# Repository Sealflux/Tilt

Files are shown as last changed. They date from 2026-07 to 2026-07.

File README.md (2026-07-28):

## Tilt
-- I put photo here once I have!

## Description
A motion-controlled keychain game console. Built around the Seeed XIAO ESP32C3 with an SSD1306 OLED and MPU6050 accelerometer. Planning to make a ball tilt game maybe

## Features
- Its a game console with an accelerometer in it!
- Play cool game or design one yourself!
- Put it on your backpack as its supposed to be a keychain thingabob
- Rechargeable Battery!
## Hardware
- Seeed Xiao ESP32-C3
- SSD1306 128x64 OLED (I2C)
- Tactile Push Button
- 3D accelerometer and 3D magnetometer
- Buzzer
- Mystery LiPo Battery(Haven't decided which one on amazon yet)
- 3D-printed case

## Bill of Materials (BOM)

| Qty | Part Name | Designator | Costs | Link/LCSC Number |
|:---:|---|:---:|:-----:|---|
| 1 | Seeed XIAO ESP32-C3 | U2 | $6.35 | [Link](https://wiki.seeedstudio.com/XIAO_ESP32C3_Getting_Started/) |
| 1 | LiPo Battery | BT1 | | I'll find one on amazon eventually |
| 1 | 0.96" OLED Display | U3 | $2.24 | [C5248080](https://www.lcsc.com/product-detail/C5248080.html) |
| 1 | Tactile Button | SW1 | $0.56 | [C2913653](https://www.lcsc.com/product-detail/C2888493.html) |
| 1 | Accelerometer | U1 | $4.04 | [C2913653](https://www.lcsc.com/product-detail/C2913653.html) |
| 1 | Capacitor – 220 nF | C3 | $0.96 | [C412252](https://www.lcsc.com/product-detail/C412252.html) |
| 2 | Ceramic Capacitor – 100 nF | C1,C2 | $0.88 | [C60474](https://www.lcsc.com/product-detail/C60474.html) |
| 1 | Aluminum Capacitor – 10 µF | C4 | $0.74 | [C192100](https://www.lcsc.com/product-detail/C192100.html) |
| 1 | Buzzer | BUZZER1 | $0.32 | [C49246964](https://www.lcsc.com/product-detail/C49246964.html) |
| 1 | 3D Printed Case | N/A | Idk whatever fliament you use makes costs dependent | N/A |
| 1 | Shipping | $52.39 | $6.20(Seeed) + $11.33(LCSC) + $6.99(Amazon) + $27.87(JLCPCB) | N/A |

## Steps To Reproduce
1. Order the PCB from whatever PCB manufacturer you like, download gerbers.zip from Production folder
2. 3D print the case, Its in the production folder. Use whatever filament you want, probably PLA.
3. Order the parts using the BOM ^^^
4. Solder the parts onto the PCB
5. Connect the LiPo battery to the PCB
6. Flash your firmware/game onto it!
7. Assemble case, sand the surfaces of top and bottom and then superglue or idk use tape. I didn't add screws for some reason.
8. Press the button and play the game!
## Firmware
this is hardware!
## Schematic

## PCB

## PCBA

## Case

## Side View Below

## Demo(Idk probably after horizons event)

Link: (TBD After I finish hardware)

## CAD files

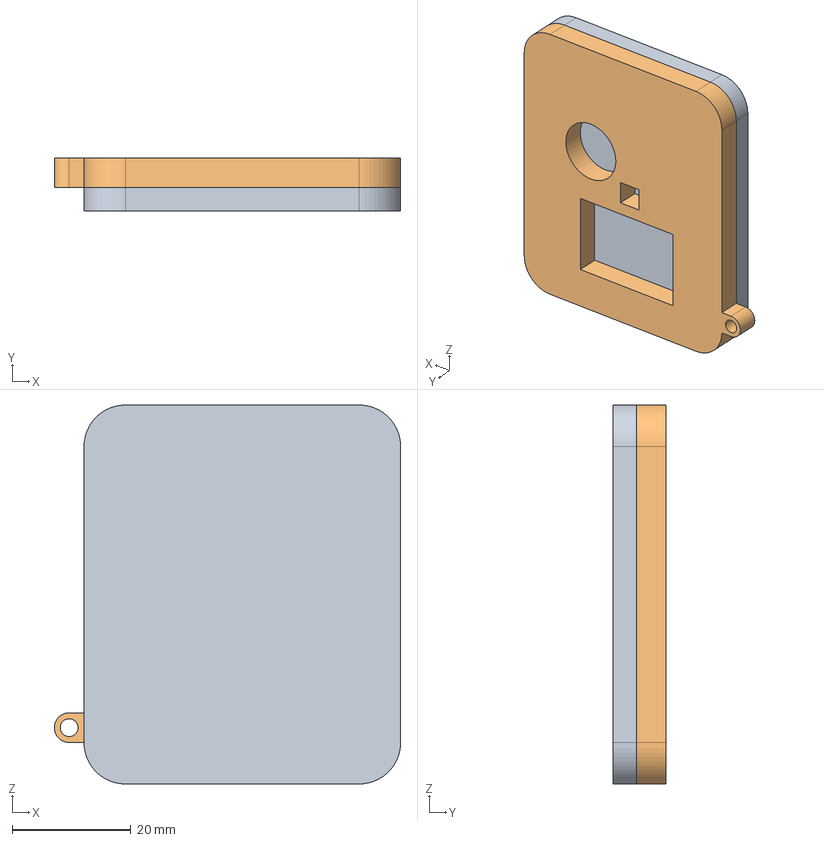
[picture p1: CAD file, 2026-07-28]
CAD/TiltCase.step
58.4 x 9.00 x 63.9 mm

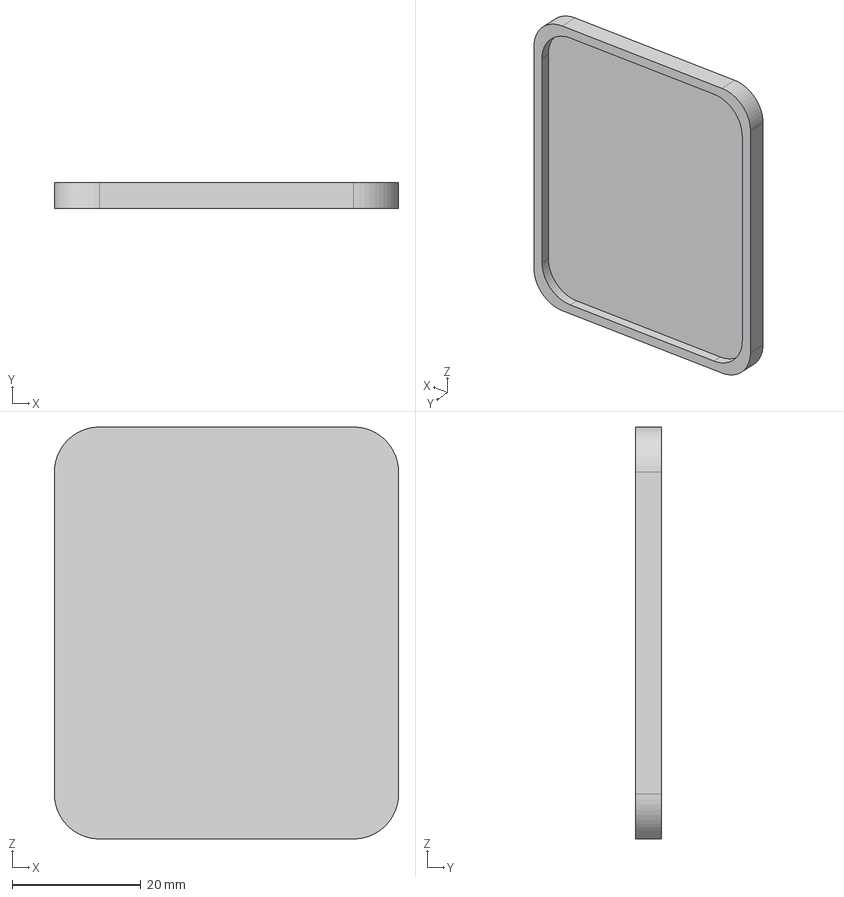
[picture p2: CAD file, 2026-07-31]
Production/Bottom.step
53.4 x 4.00 x 63.9 mm

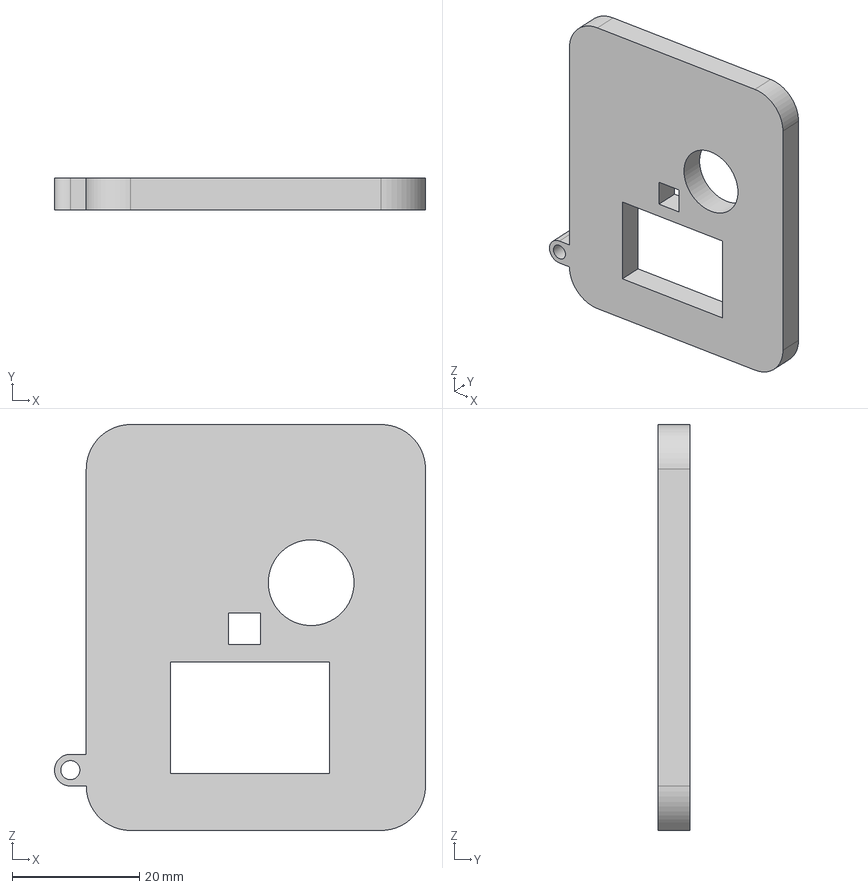
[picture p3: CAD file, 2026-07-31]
Production/Top.step
58.4 x 5.00 x 63.9 mm

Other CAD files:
CAD/TiltCase.f3d

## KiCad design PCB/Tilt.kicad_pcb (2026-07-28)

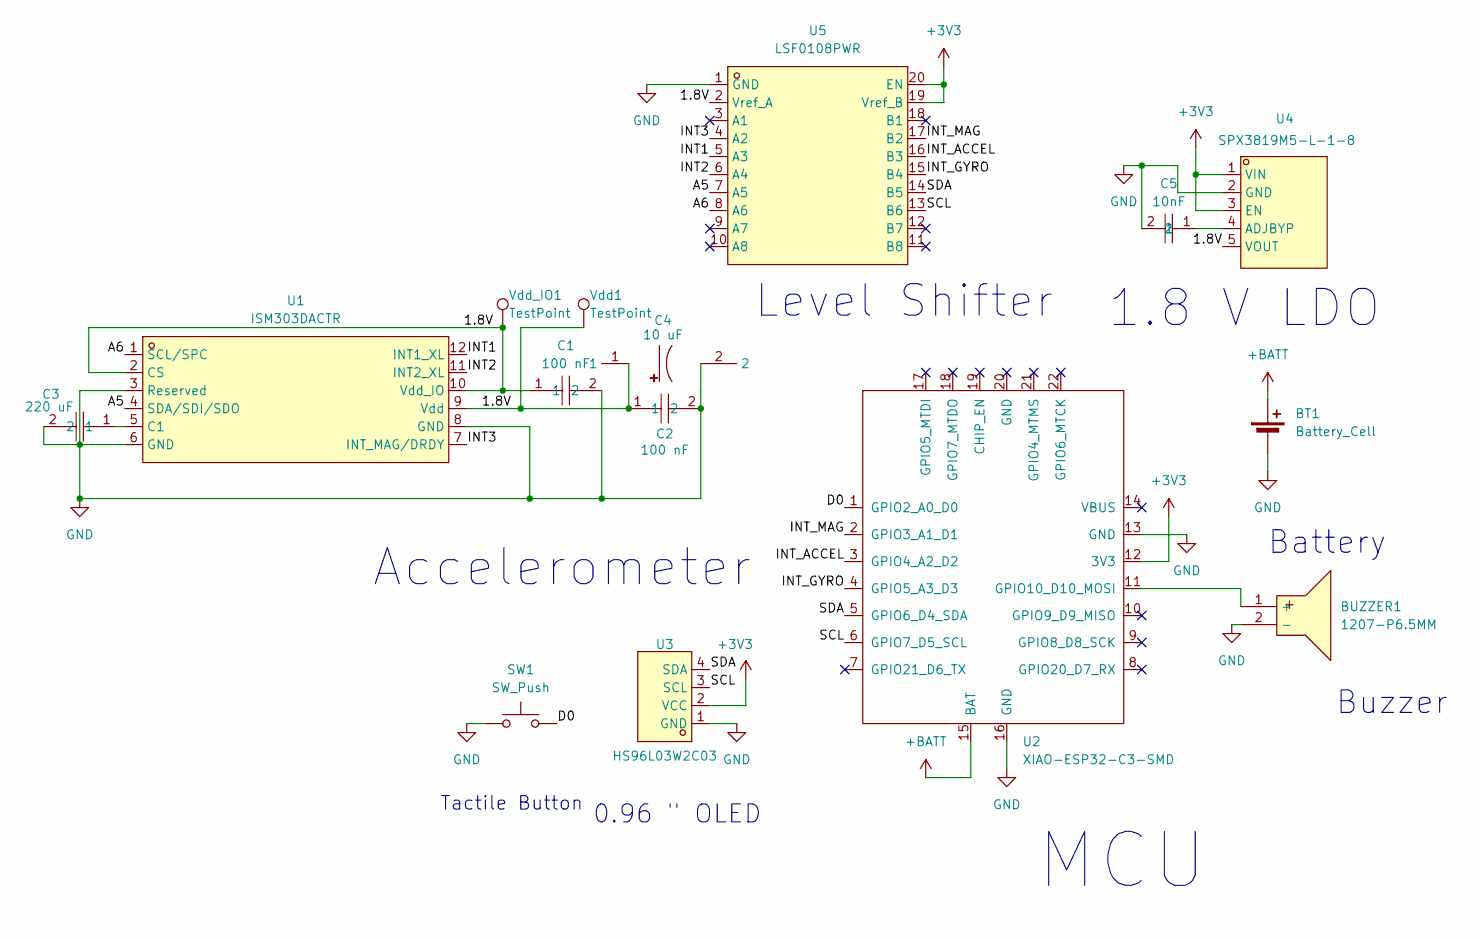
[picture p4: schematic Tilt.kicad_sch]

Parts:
BT1: Battery_Cell; PinHeader_1x02_P2.54mm_Vertical
BUZZER1: 1207-P6.5MM; BUZ-TH_BD12.5-P6.50-D1.4; MPN 1207-P6.5MM; LCSC Part C49246964
C1, C2: 100 nF; C0402; MPN CC0402KRX7R7BB104; LCSC Part C60474
C3: 220 uF; C1206; MPN GRM31CR60J227ME11L; LCSC Part C412252
C4: 10 uF; CAP-TH_BD5.0-P2.00-D0.8-FD; MPN ECR1HBK100MLL050011; LCSC Part C192100
C5: 10nF; C0603; MPN CC0603KRX7R9BB103; LCSC Part C100042
SW1: SW_Push; SW-TH_4P-L4.5-W4.5-P3.00-LS4.8
U1: ISM303DACTR; VLGA-12_L2.0-W2.0-P0.50-BL; MPN ISM303DACTR; LCSC Part C2913653
U2: XIAO-ESP32-C3-SMD; XIAO-ESP32-C3-DIP-SMD
U3: HS96L03W2C03; OLED-TH_L27.8-W27.2-P2.54_C9900033791; MPN HS96L03W2C03; LCSC Part C5248080
U4: SPX3819M5-L-1-8; SOT-23-5_L3.0-W1.7-P0.95-LS2.8-TL; MPN SPX3819M5-L-1-8/TR; LCSC Part C24639
U5: LSF0108PWR; TSSOP-20_L6.5-W4.4-P0.65-LS6.4-BL; MPN LSF0108PWR; LCSC Part C190219
Vdd1: TestPoint; TestPoint_Pad_D2.5mm
Vdd_IO1: TestPoint; TestPoint_Pad_D2.5mm

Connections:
+3V3: U2.12 (3V3), U3.2 (VCC), U4.1 (VIN), U4.3 (EN), U5.19 (Vref_B), U5.20 (EN)
+BATT: BT1.1 (+), U2.15 (BAT)
/1.8V: C1.1, C2.1, C4.1, U1.2 (CS), U1.9 (Vdd), U1.10 (Vdd_IO), U4.5 (VOUT), U5.2 (Vref_A), Vdd1.1 (1_1), Vdd_IO1.1 (1_1)
/A5: U1.4 (SDA/SDI/SDO), U5.7 (A5)
/A6: U1.1 (SCL/SPC), U5.8 (A6)
/D0: SW1.2, U2.1 (GPIO2_A0_D0)
/INT1: U1.12 (INT1_XL), U5.5 (A3)
/INT2: U1.11 (INT2_XL), U5.6 (A4)
/INT3: U1.7 (INT_MAG/DRDY), U5.4 (A2)
/INT_ACCEL: U2.3 (GPIO4_A2_D2), U5.16 (B3)
/INT_GYRO: U2.4 (GPIO5_A3_D3), U5.15 (B4)
/INT_MAG: U2.2 (GPIO3_A1_D1), U5.17 (B2)
/SCL: U2.6 (GPIO7_D5_SCL), U3.3 (SCL), U5.13 (B6)
/SDA: U2.5 (GPIO6_D4_SDA), U3.4 (SDA), U5.14 (B5)
GND: BT1.2 (-), BUZZER1.2 (-), C1.2, C2.2, C3.2, C4.2, C5.2, SW1.1, U1.3 (Reserved), U1.6 (GND), U1.8 (GND), U2.13 (GND), U2.16 (GND), U3.1 (GND), U4.2 (GND), U5.1 (GND)
unnamed: BUZZER1.1 (+), U2.11 (GPIO10_D10_MOSI)
unnamed: C3.1, U1.5 (C1)
unnamed: C5.1, U4.4 (ADJBYP)

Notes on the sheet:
Tactile Button
1.8 V LDO
Buzzer
MCU
Accelerometer
Level Shifter
0.96 " OLED
Battery

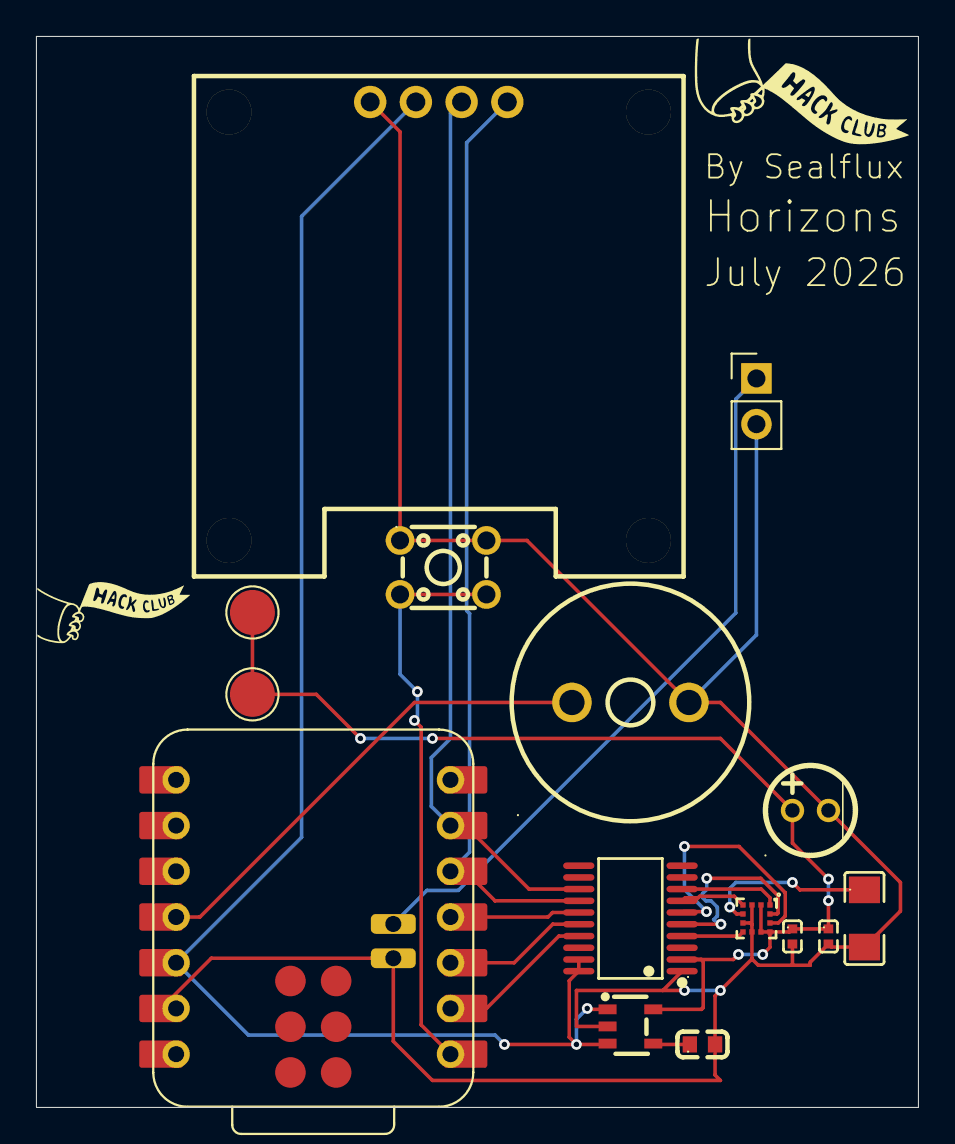
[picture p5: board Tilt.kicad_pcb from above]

Board: 2 copper layers, 49.0 x 59.5 mm, 15 parts (0 on the bottom side), 18 nets.

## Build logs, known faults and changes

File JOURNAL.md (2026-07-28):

## July 20th: Setting everything up and doing schematic, also BOM.
Alright I finished setting up the repo, now i"m gonna find parts for the BOM from LCSC. We will be using the Seeed XIAO ESP32-C3 because its tiny and it has bulit in battery charging and I"m quite experienced with it before
While I was designing the schematic, I feel like there should probably a button to turn on the game console otherwise it'll just be draining power. I also added an OLED as how else would you be able to see the game? I used net labels for the SCL and SDA that are shared between the OLED and the accelerometer For the accelerometer for the PCB, we need a capacitor of 220 nF, a capacitor of 10 uF, a capacitor of 100 nF, and finally a capacitor of 100nF. Current BOM:
1 Seeed XIAO ESP32-C3 | https://wiki.seeedstudio.com/XIAO_ESP32C3_Getting_Started/
1 LiPo Battery
1 0.96 " OLED | https://www.lcsc.com/product-detail/C5248080.html
1 Tactile Button | https://www.lcsc.com/product-detail/C2913653.html
1 Accelerometer | https://www.lcsc.com/product-detail/C2913653.html
1 Capacitor Of 220 nF | https://www.lcsc.com/product-detail/C412252.html
2 Ceramic Capacitors Of 100 nF | https://www.lcsc.com/product-detail/C60474.html
1 Aluminum Capacitor of 10 uF | https://www.lcsc.com/product-detail/C192100.html
1 Buzzer | https://www.lcsc.com/product-detail/C49246964.html

I've found all the parts and I've imported them to KICAD, now I just need to wire them and stuff!
I've decided to add a buzzer for sound of the game!. I finally finished wiring up the accelerometer, it had a lot of things that I needed to read the PDF for. Because I'm using I2C because my MCU is the Seeed XIAO ESP32-C3. I needed to wire the CS of the accelerometer to the VDD_IO. . Everything else to wire was relatively simple as they had a very nice diagram! 

I also have to remember that I need to program/configure the INT signals of the accelerometer over I2C using the MCU. Otherwise they won't do anything. I finished the schematic!


I'll do the PCB tomorrow and update the README with the BOM along with proper costs!

### Lapse Link: https://lapse.hackclub.com/timelapse/DgCehcromlk1

## July 23rd: Fixing my schematic wit level shifters and LDO.

Umm I kinda had a 3 day break from this project but I'm back and locked in. First off, I was checking the schematic for my accelerometer and realized that I didn't connect any power to it. Then I checked the datasheet and the accelerometer needs voltage between -0.3 and 2.2 Volts which means I need a LDO for the accelerometer. The recommended voltage will be 1.8 Volts so I need a LDO for that. I just realized that I need a level shifter for the accelerometer for the SDA/SCL because in the datasheet it said explicitly, that supply voltage on any pin should never exceed 2.2 Volts which means the 3.3 Volts feeding from the ESP32-C3's SDA/SCL into the acclerometer needs to be shifted down to 1.8 volts and then the data out needs to be shifted back to 3.3 Volts back to the ESP32-C3... I'll probably handle that tomorrow or today, depending on my progress.  
Yeah I finished the schematic* if I don't add anything more.

### Lapse Link: https://lapse.hackclub.com/timelapse/iDyg0CzmcFjp

## July 24th: Doing the PCB layout and also changing schematic at the same time

I began doing the PCB layout and routing traces as well as simanutelous, I mean chaging the schematic at the same time to make routing my traces a lot easier although my PCB is still a hot mess, its good enough I guess. Also had me second guessing my edge cut efficiency. So yeah thats basically what I did today, I'll do the CAD tomorrow and then the subsequent days will simply be me making a game to put on the hardware! yippie!. The reason why I made this project is that I'll have it on my backpack and then soemeone will ask whats that and I can show them how to use it and say that the game and the console itself I fully made which is sick!
Finished schematic*: 
Finished PCB*: 
Finished PCBA*: 

### Lapse Link: https://lapse.hackclub.com/timelapse/NZZQcLnYxApk

## July 26th: Doing and finishing the CAD/Case

I began and finished modeling the case for Tilt. I'll begin making the firmware/designing the game that will run on Tilt tomorrow. But so far the hardware side of Tilt is done!
Finished Case*: 

### Lapse Link: https://lapse.hackclub.com/timelapse/da-rFHXiI8Pn

## July 27th: Finishing the Cad + Coding the game

In the lapse, I finished the cad by adding the model of the PCB to make it look better.
Sideview Of Cad: 
For me coding the game, I didn't record it using lapse because thats what hackatime is for :D. I also added the PCB and Cad files! Also I realized that I can't code the game unless I have the hardware or a way to simulate it, which I found called Wokwi.com, however I need to set up the same design visually in the website so i'll do that tomorrow with lapse and then hackatime my code! I also setup skeleton of the tilt game by adding a folder and ino.

### Lapse Link: https://lapse.hackclub.com/timelapse/J4MSxDjkK73_

## July 28th: Shipping hardware

I've decided to simply have the firmware of this project/game of this project on a seperate repo, this will simply be the hardware!

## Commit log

2026-07-20 Added MIT License along with Journal and uhh skeleton/frame
2026-07-20 ## July 20th: Setting everything up and doing schematic, also BOM.
2026-07-21 Made the BOM in readme with costs!
2026-07-21 Modify BOM header to include 'Link'
    Updated the BOM table to include 'Link' in the header.
2026-07-24 ## July 23rd: Fixing my schematic wit level shifters and LDO.
2026-07-24 ## July 24th: Doing the PCB layout and also changing schematic at the same time
2026-07-26 ## July 26th: Doing and finishing the CAD/Case
2026-07-28 ## July 27th: Finishing the Cad + Coding the game
    [Bottom.stl, Tilt.kicad_pcb, Tilt.kicad_sch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]
2026-07-31 Replaced .stl with .step files to resubmit!
    [Bottom.step, Bottom.stl, Top.step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]
